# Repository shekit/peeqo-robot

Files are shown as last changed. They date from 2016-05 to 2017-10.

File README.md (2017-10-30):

# Peeqo
Thank you for making this the **~highest~ second highest voted DIY project** everr on Reddit! 
https://www.reddit.com/r/DIY/comments/5h15f4/i_built_a_desktop_robot_that_responds_entirely_in/

Check out the **video** here: https://youtu.be/ApAzIJ3jQtw

# Hardware

I have separated out the hardware elements into a seperate repo. You can find that here https://github.com/shekit/peeqo-robot-hardware

# Setting up the Pi:

This is a detailed guide on getting your Pi up and running:

### Setup up SD Card on Pi:

1. Download Raspbian Jessie with Pixel (https://www.raspberrypi.org/downloads/raspbian/)
- Kernel Version - 4.4
- Release Date - 11 - 01 - 2017 or latest version
- Version - January 2017  or latest version
2. Unzip File
- Mac OSX has problems unzipping files which unzip to more than 4gb
- Go to Terminal and unzip file with command
- tar xzvf /path/to/zip/file
3. Download Etcher from resin.io (https://etcher.io/)
4. Download SDFormatter and clean format SD card(not quick clean) -(https://www.sdcard.org/downloads/formatter_4/)
- Sometimes SD cards larger than 32GB may not work on pi
- If Pi RED LED is on, no green LED blinking, it means it cannot read the SD card
5. Transfer unzipped .img file to SD card using Etcher (etcher.io)
6. Plug SD card into Pi and boot up
7. Connect to wifi or plug in ethernet cable

### Initial Setup:

1. Go to Menu > Preferences > Raspberry Pi Config
- Set Keyboard to US
- Set Locale to your Locale
- Expand Filesystem
2. Reboot
3. Run commands in terminal to update Raspbian for recent bug fixes:
 - `sudo apt-get update` OR `sudo apt update`
 - `sudo apt-get dist-upgrade` OR `sudo apt full-upgrade`
4. Enable SSH and i2C
- `sudo raspi-config`
- Interfacing Options > SSH > Enabled
- Interfacing Options > i2c > Enabled
5. Enable overclocking or uncomment in /boot/config.txt `arm_freq=800`
6. `sudo apt install apt-transport-https`
7. Install python pillow
- `pip install pillow`
- Make sure you are using python 2.7 not 3.0+

### Update Node:

1. Raspbian ships with node v0.10.29 which will not work, have to update it
2. Remove Old Version of Node
- `sudo apt-get remove nodered -y`  (-y flag just says yes instead of requiring user input)
- `sudo apt-get remove nodejs nodejs-legacy -y`
- `sudo apt-get remove npm -y`
3. Install Latest Node Version (install version 6)
- `sudo curl -sL https://deb.nodesource.com/setup_6.x | sudo -E bash -`
- `sudo apt-get install nodejs -y`
4. Check node and npm version
- `node -v`
- Output should be v6.10.10 or higher
- `npm -v`
- Output should be 3.10.10 or higher

### Install Electron:

1. Install Electron globally (currently have v1.6.2)
- `sudo npm install -g electron`
2. If this doesn’t work
```
rm -rf ~/.electron
mkdir ~/.electron
chmod 777 ~/.electron
sudo rm /usr/bin/electron
sudo npm -g install electron
```
### Clone this repo:

```
cd ~
git clone https://github.com/shekit/peeqo-robot
```

### Start App on Boot/Startup:

1. Change into directory
 - `~/.config/autostart`
 - You may need to create this directory if it doesn't exist
2. Add and edit .desktop file with any name inside this directory
- `sudo nano peeqo.desktop`
3. Edit this file
``` 
[Desktop Entry]
	Type=Application
	Exec=./launch.sh
```
4. Create launcher script at root directory
```sudo nano launch.sh
sudo chmod +x launch.sh
```
5. Edit launch script
```
#!/bin/bash
cd /path/to/electron/app // this should be where the directory exists on your pi
sudo electron main.js
```

### Setup Mic:

1. Plug Sound Card into USB
2. Plug speaker and mic into soundcard
3. Do `arecord -l` and `aplay -l` to see the number of your device - whether it’s 0,1,2
4. Edit alsa.conf (might have to change to 1 or 2 depending on whether you have a camera plugged in)
```
sudo nano /usr/share/alsa/alsa.conf
defaults.ctl.card 0 > defaults.ctl.card 1
defaults.pcm.card 0 > defaults.pcm.card 1
defaults.pcm.device 0 > defaults.pcm.device 1
```
5. Edit aliases.conf

`sudo nano /lib/modprobe.d/aliases.conf`
- Comment out below option or it will override previous changes on startup
```
options snd-usb-audio index=-2 (comment this out with a # before)
```
- THIS MAY BE CAUSING AN ERROR, dont do this and see if it helps
- Check order modules load in
`cat /proc/asound/modules`

6. Edit .asoundrc
```
nano .asoundrc
pcm.!default{
	type asym
	playback.pcm {
		type plug
		slave.pcm “hw:1,0”  
#this first number is the number of the usb device
	}

	capture.pcm {
		type plug
		slave.pcm “hw:1,0”
 #this is the mic usb number, maybe 2 if camera is included
}
}
```
7. Check if this works instead ( this worked on one pi not running pixel)
`pcm.!default { type plug slave { pcm "hw:1,0" } } ctl.!default { type hw card 1 }`
8. If you don’t use plugs you will get following error with arecord
`arecord: set_params:1233: Sample format non available Available formats: - S16_LE`

### Setup Bluetooth:

1. `hcitool | grep ver` -- make sure it’s higher than 5.x.x
2. Stop Bluetooth Daemon bluetoothd
```
sudo systemctl stop bluetooth
sudo systemctl status bluetooth #should show status ‘quitting’
sudo systemctl disable bluetooth #for it to persist after reboot
```
3. Power up bluetooth adapter
`sudo hciconfig hci0 up`
4. Install necessary libraries
`sudo apt-get install bluetooth bluez libbluetooth-dev libudev-dev`
5. Allow to run without root/sudo
```
sudo apt-get install libcap2-bin
sudo setcap cap_net_raw+eip $(eval readlink -f `which electron`)
```
- This grants electron cap_net_raw priveleges to start/stop ble advertising
(this is not working right now)
6. Do all this before installing an app with bleno

### Remove Mouse Cursor and prevent screen from going off:

`sudo nano /etc/lightdm/lightdm.conf`
- Uncomment any line saying xserver-command=X
- Write command
`xserver-command=X -nocursor -s 0 -dpms`

### Manga Screen Settings:

```
sudo nano /boot/config.txt
hdmi_force_hotplug=1 (if not already there)
config_hdmi_boost=4
overscan_left=0
overscan_right=0
overscan_top=0
overscan_bottom=0
disable_overscan=1
display_rotate=1
	
hdmi_cvt=480 800 60 6
#hdmi_group=2
#hdmi_mode=87
#hdmi_drive=2
```

### Increase USB Current:

```
sudo nano /boot/config.txt
max_usb_current=1
```
### Run app:

```
cd /path/to/folder/electron
sudo electron main.js
```

# Steps Ahead

Yes, there's still work to be done. I will keep chipping away at it. Any contributions/feedback are welcome!

Let's make Peeqo the best community built robot ever!

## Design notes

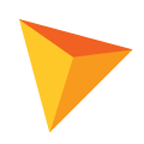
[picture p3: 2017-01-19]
cordova/www/img/xxhdpi.png

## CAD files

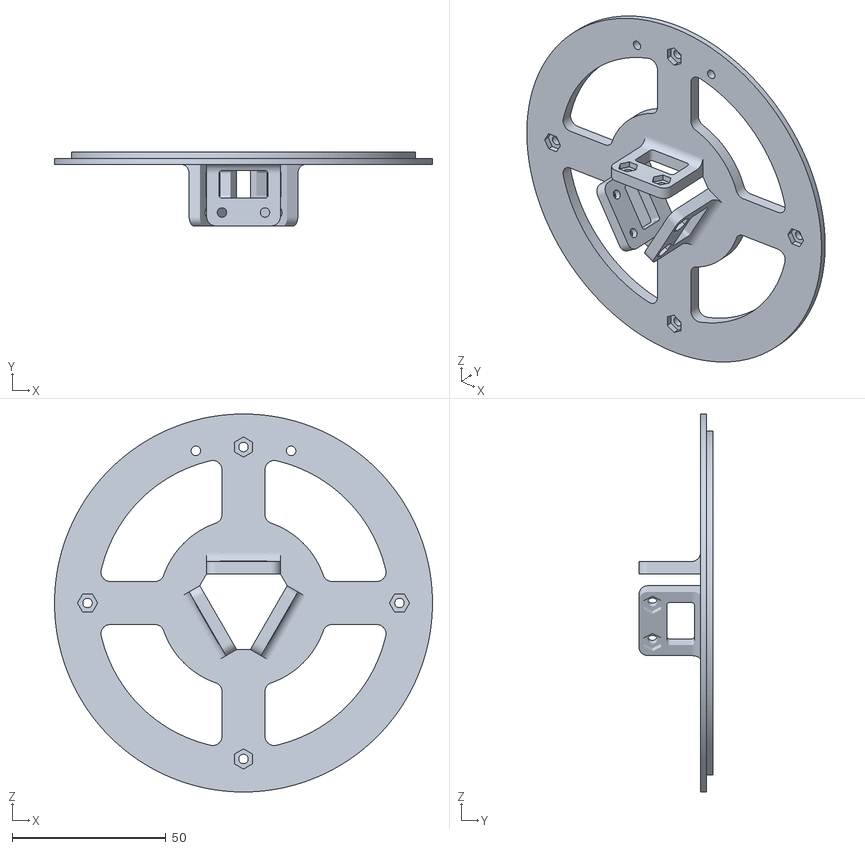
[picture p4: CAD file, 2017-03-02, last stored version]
stl_files/stewart_top.stl
123.0 x 24.0 x 123.0

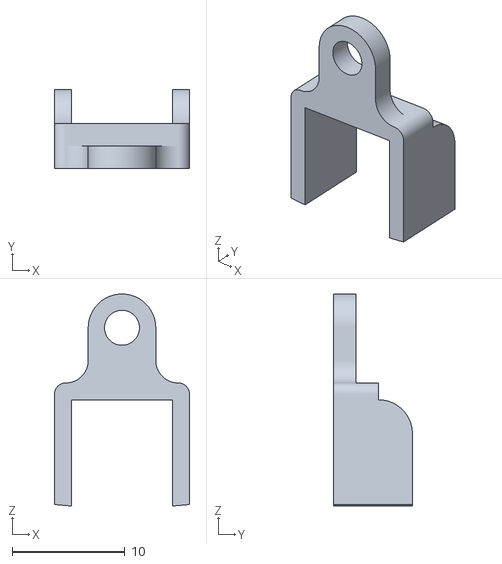
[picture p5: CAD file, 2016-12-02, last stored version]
stl_files/power_inlet_holderx1.stl
12.0 x 7.00 x 18.8

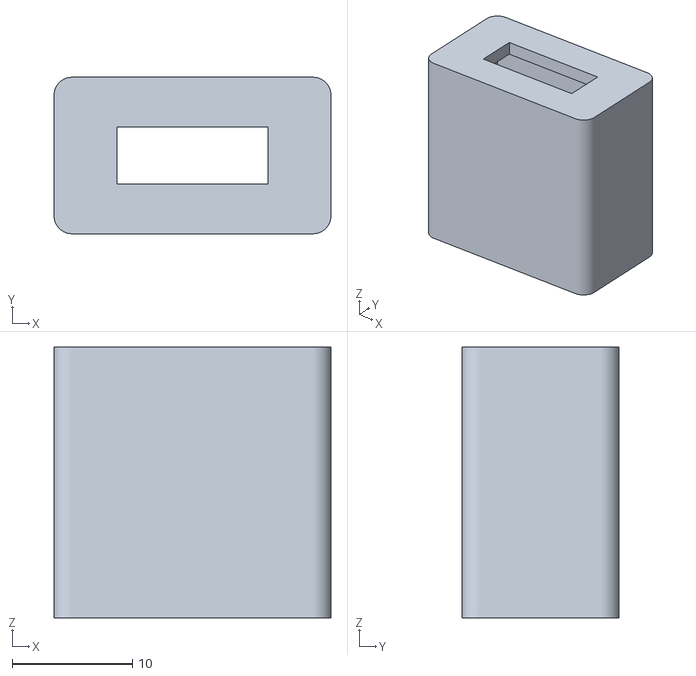
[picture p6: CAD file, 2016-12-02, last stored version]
stl_files/sabrent_sound_card_coverx1.stl
23.0 x 13.0 x 22.5

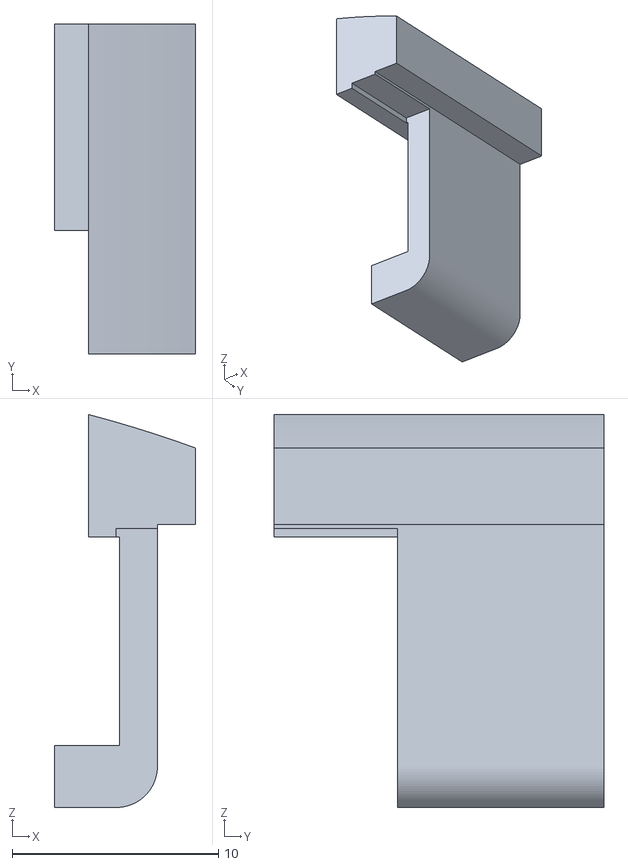
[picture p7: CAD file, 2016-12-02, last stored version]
stl_files/servo_slide_clampx3.stl
6.85 x 16.0 x 19.0

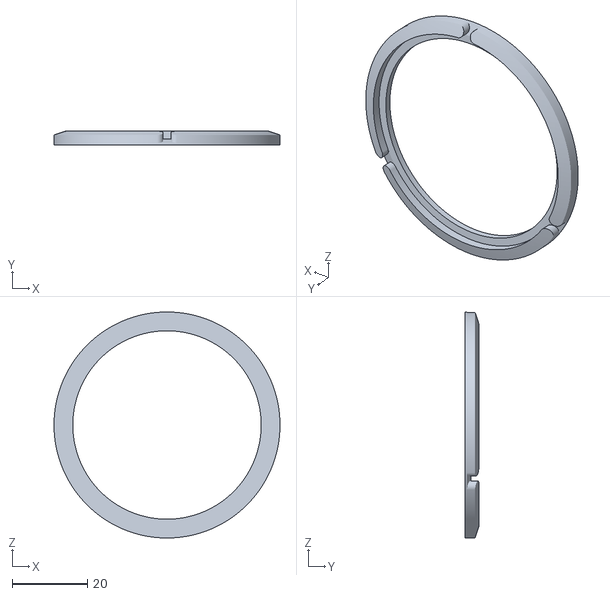
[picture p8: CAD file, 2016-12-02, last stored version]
stl_files/led_ringx1.stl
60.0 x 3.63 x 60.0

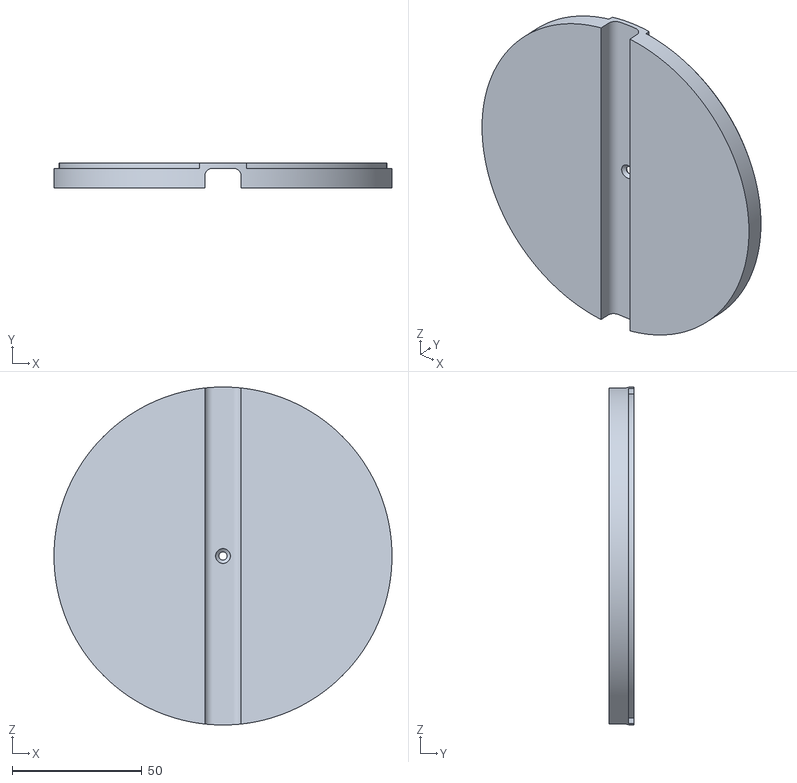
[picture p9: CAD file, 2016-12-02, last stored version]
stl_files/base_feetx1.stl
130.0 x 9.50 x 130.0

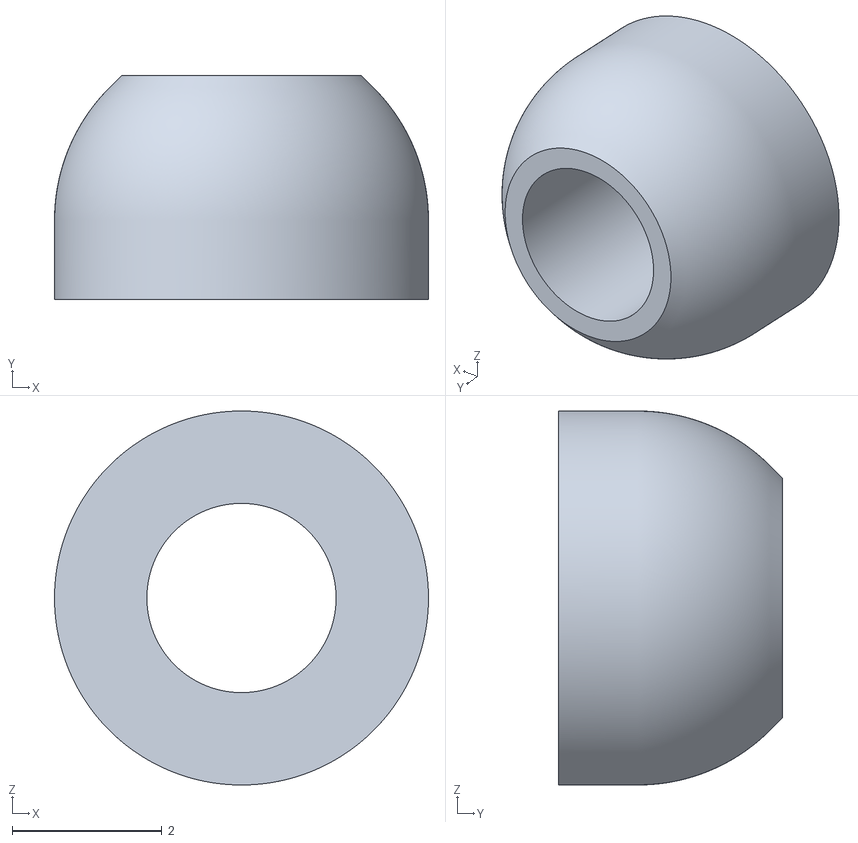
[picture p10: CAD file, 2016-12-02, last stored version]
stl_files/3mmspacerx12.stl
5.00 x 3.00 x 5.00

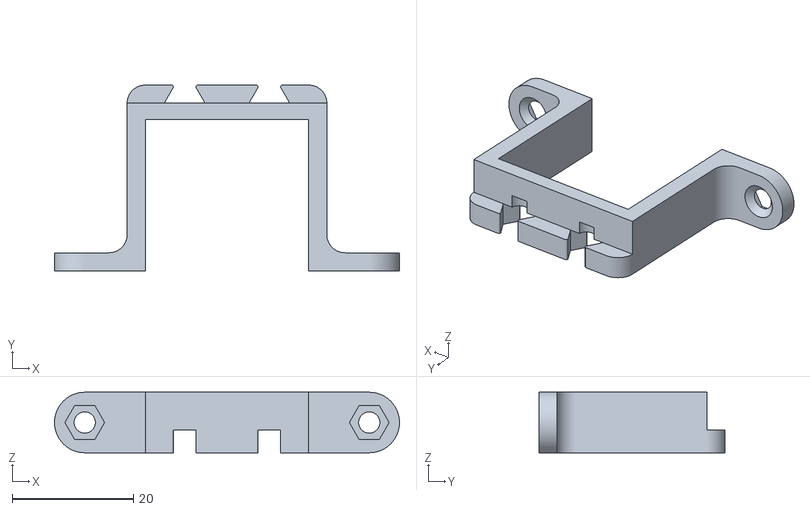
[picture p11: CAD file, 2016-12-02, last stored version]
stl_files/servo_holderx3.stl
57.0 x 30.7 x 10.0

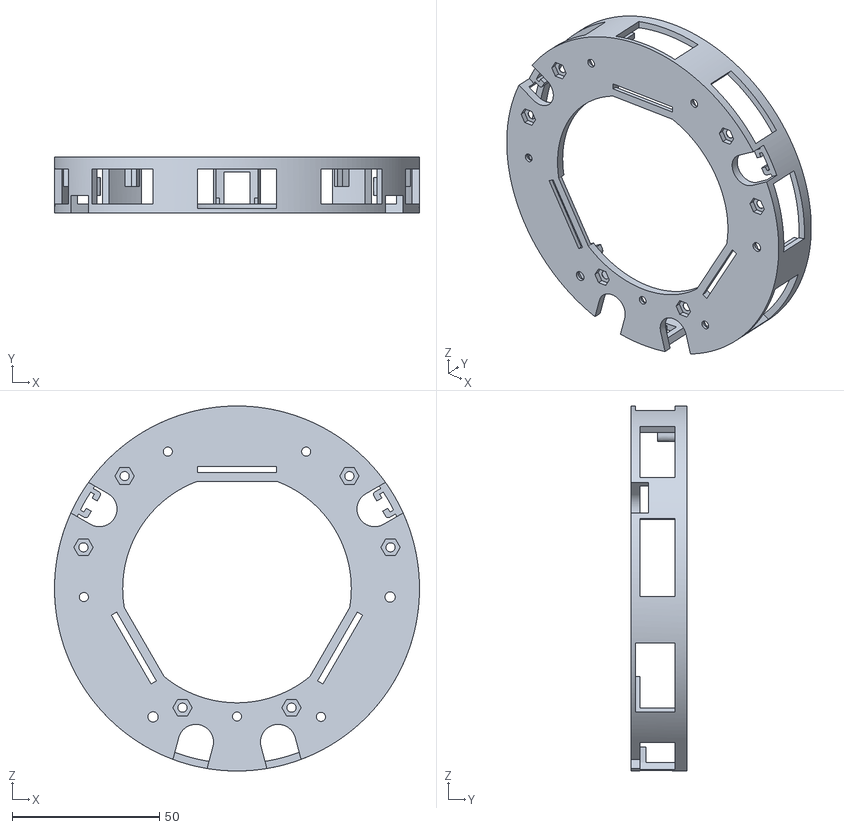
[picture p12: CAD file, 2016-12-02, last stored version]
stl_files/stewart_basex1.stl
124.0 x 19.0 x 124.0

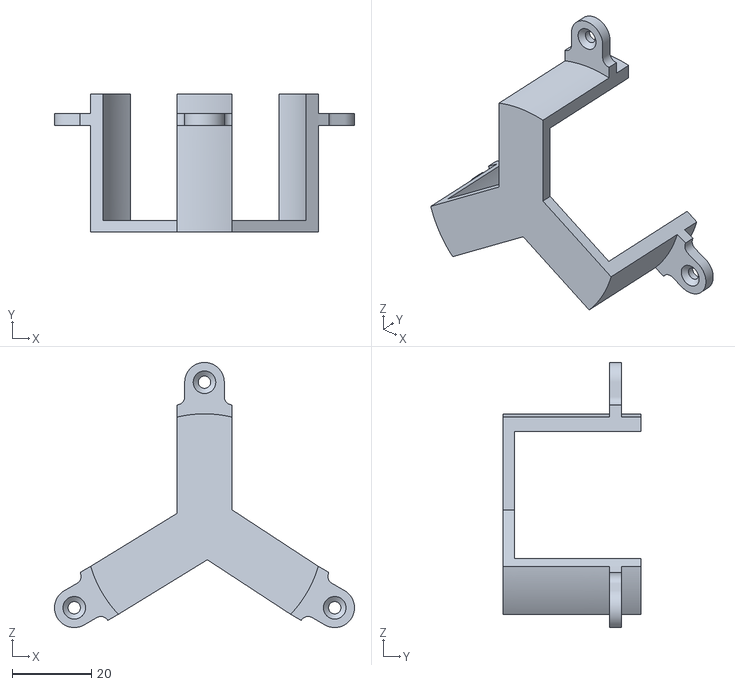
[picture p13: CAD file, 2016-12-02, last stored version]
stl_files/speaker_clampx1.stl
75.8 x 35.0 x 67.0

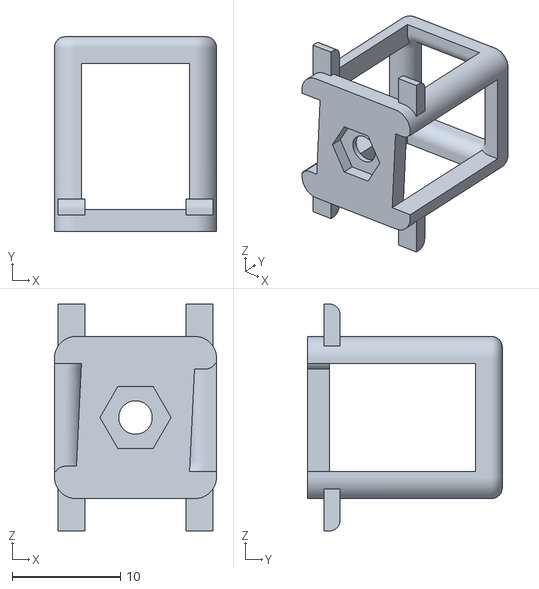
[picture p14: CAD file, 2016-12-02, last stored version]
stl_files/wire_organizerx1.stl
15.0 x 18.0 x 21.0

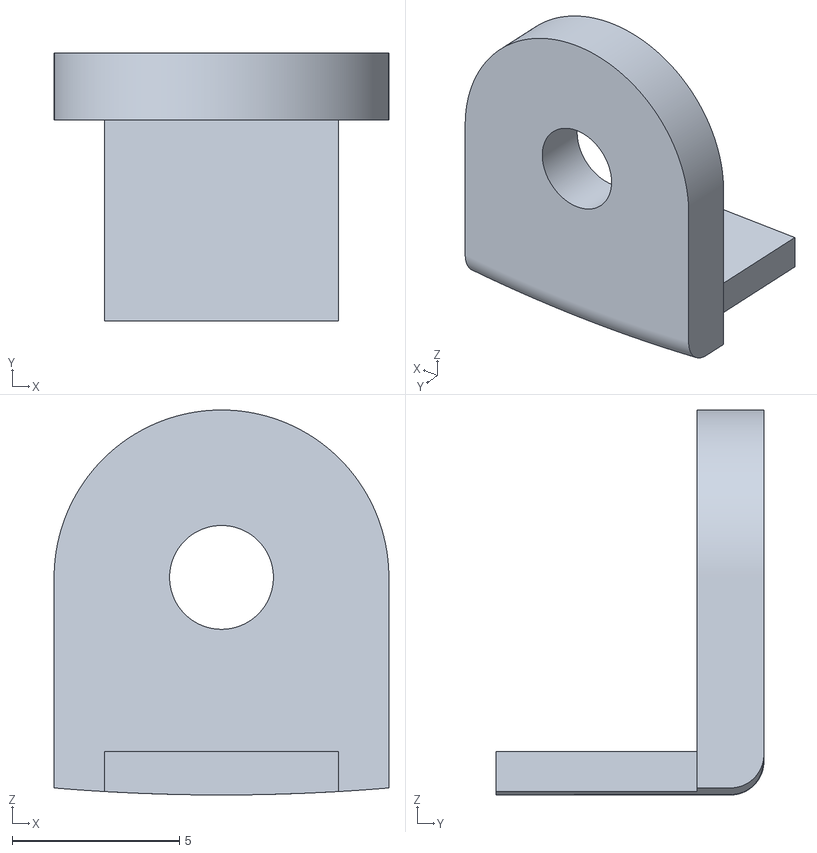
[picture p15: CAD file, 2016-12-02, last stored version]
stl_files/circuit_holderx2.stl
10.0 x 8.00 x 11.5

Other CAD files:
stl_files/servo_slide_clamp_mirrowx3.stl

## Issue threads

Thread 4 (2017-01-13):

Consider using Sonus

evancohen, 2017-01-13:
Hey @shekit, love the project. Since you're already using the snowboy node module that I wrote I thought I would recommend [Sonus](https://github.com/evancohen/sonus): It uses snowboy for keyword spotting and has built-in streaming recognition, which might make things a little easier on you, given you are trying to open source.

I currently use it in an Electron project so you have something to base it off of: https://github.com/evancohen/smart-mirror

I'd be happy to send a PR if you'd care to point me in the right direction :)

shekit, 2017-01-13:
hey @evancohen, love your project too.. still have to update this repo, been working in a test repo where I built the entire snowboy google integration only to find your library and realize you do it much better! so yes already switchin to Sonus on my test repo :)

evancohen, 2017-01-13:
Awesome! If you need any help, either adding features to Sonus (or otherwise), I'd be happy to lend a hand.

I am super passionate about (and am trying to increase awareness around) voice interfaces. Would you mind linking to Sonus from your YouTube video/imgur post? That'd be really awesome :)

shekit, 2017-01-13:
Done! Added to the imgur post under the voice recognition section :)

evancohen, 2017-01-13:
Thanks! Once things cool down a bit for you (I imagine things are a bit crazy right now) it'd be really fun to collaborate on something. Ping me sometime!

Closed 2017-01-13.

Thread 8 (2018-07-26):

Documentation of the architecture

assadollahi, 2018-07-26:
Hi thanks für sharing this awesome project, it would be cool to understand the architecture better, like:

- what is the architecture from bird's eye view?
- what kind of speech recognition do you use (is it simply google or amazon?)
- what gif server do you query
- what is the main programming language (node,js, i guess, why not python?)
- what exactly do you do with bluetooth (or why is it necessary), to control the lamp?
- how do you manage dialogs (do you use a package like Jasper)
- how do you "load spotify" on the raspberry pi (i've seen projects doing that)
- it's nice that you use arduino for controlling the servos, but people need to know how to wire it up, at least roughly (i.e. how many servos do you use and what are their functions), pictures from the inside of the neck would be nice.

cheers, keep up the good work!

shekit, 2019-07-01:
this has been moved to a new repo https://github.com/shekit/peeqo. If you have a look at the wiki it contains a tutorial on how to setup a custom command which covers a lot of these high level questions

Closed 2019-07-01.

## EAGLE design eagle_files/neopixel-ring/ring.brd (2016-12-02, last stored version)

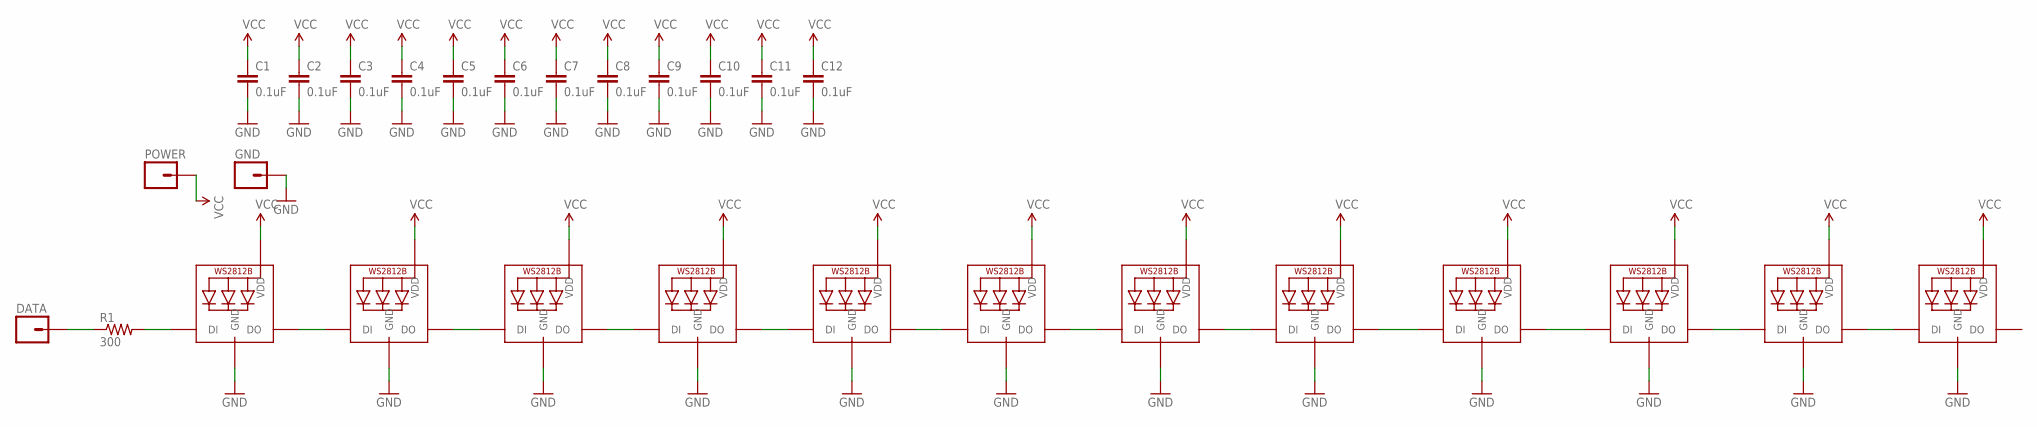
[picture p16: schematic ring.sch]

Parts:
C1, C2, C3, C4, C5, C6, C7, C8, C9, C10, C11, C12: 0.1uF; 0603-CAP
DATA: M01PTH; 1X01
GND: M01PTH; 1X01
LED1, LED2, LED3, LED4, LED5, LED6, LED7, LED8, LED9, LED10, LED11, LED12: WS2812B5050; WS2812B
POWER: M01PTH; 1X01
R1: 300; 0603-RES

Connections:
GND: C1.2, C2.2, C3.2, C4.2, C5.2, C6.2, C7.2, C8.2, C9.2, C10.2, C11.2, C12.2, GND.1, LED1.3-GND (GND), LED2.3-GND (GND), LED3.3-GND (GND), LED4.3-GND (GND), LED5.3-GND (GND), LED6.3-GND (GND), LED7.3-GND (GND), LED8.3-GND (GND), LED9.3-GND (GND), LED10.3-GND (GND), LED11.3-GND (GND), LED12.3-GND (GND)
unnamed: LED1.4-DIN (DI), R1.2
unnamed: DATA.1, R1.1
unnamed: LED1.2-DOUT (DO), LED2.4-DIN (DI)
unnamed: LED2.2-DOUT (DO), LED3.4-DIN (DI)
unnamed: LED3.2-DOUT (DO), LED4.4-DIN (DI)
unnamed: LED4.2-DOUT (DO), LED5.4-DIN (DI)
unnamed: LED5.2-DOUT (DO), LED6.4-DIN (DI)
unnamed: LED6.2-DOUT (DO), LED7.4-DIN (DI)
unnamed: LED7.2-DOUT (DO), LED8.4-DIN (DI)
unnamed: LED8.2-DOUT (DO), LED9.4-DIN (DI)
unnamed: LED9.2-DOUT (DO), LED10.4-DIN (DI)
unnamed: LED10.2-DOUT (DO), LED11.4-DIN (DI)
unnamed: LED11.2-DOUT (DO), LED12.4-DIN (DI)
VCC: C1.1, C2.1, C3.1, C4.1, C5.1, C6.1, C7.1, C8.1, C9.1, C10.1, C11.1, C12.1, LED1.1-VDD (VDD), LED2.1-VDD (VDD), LED3.1-VDD (VDD), LED4.1-VDD (VDD), LED5.1-VDD (VDD), LED6.1-VDD (VDD), LED7.1-VDD (VDD), LED8.1-VDD (VDD), LED9.1-VDD (VDD), LED10.1-VDD (VDD), LED11.1-VDD (VDD), LED12.1-VDD (VDD), POWER.1

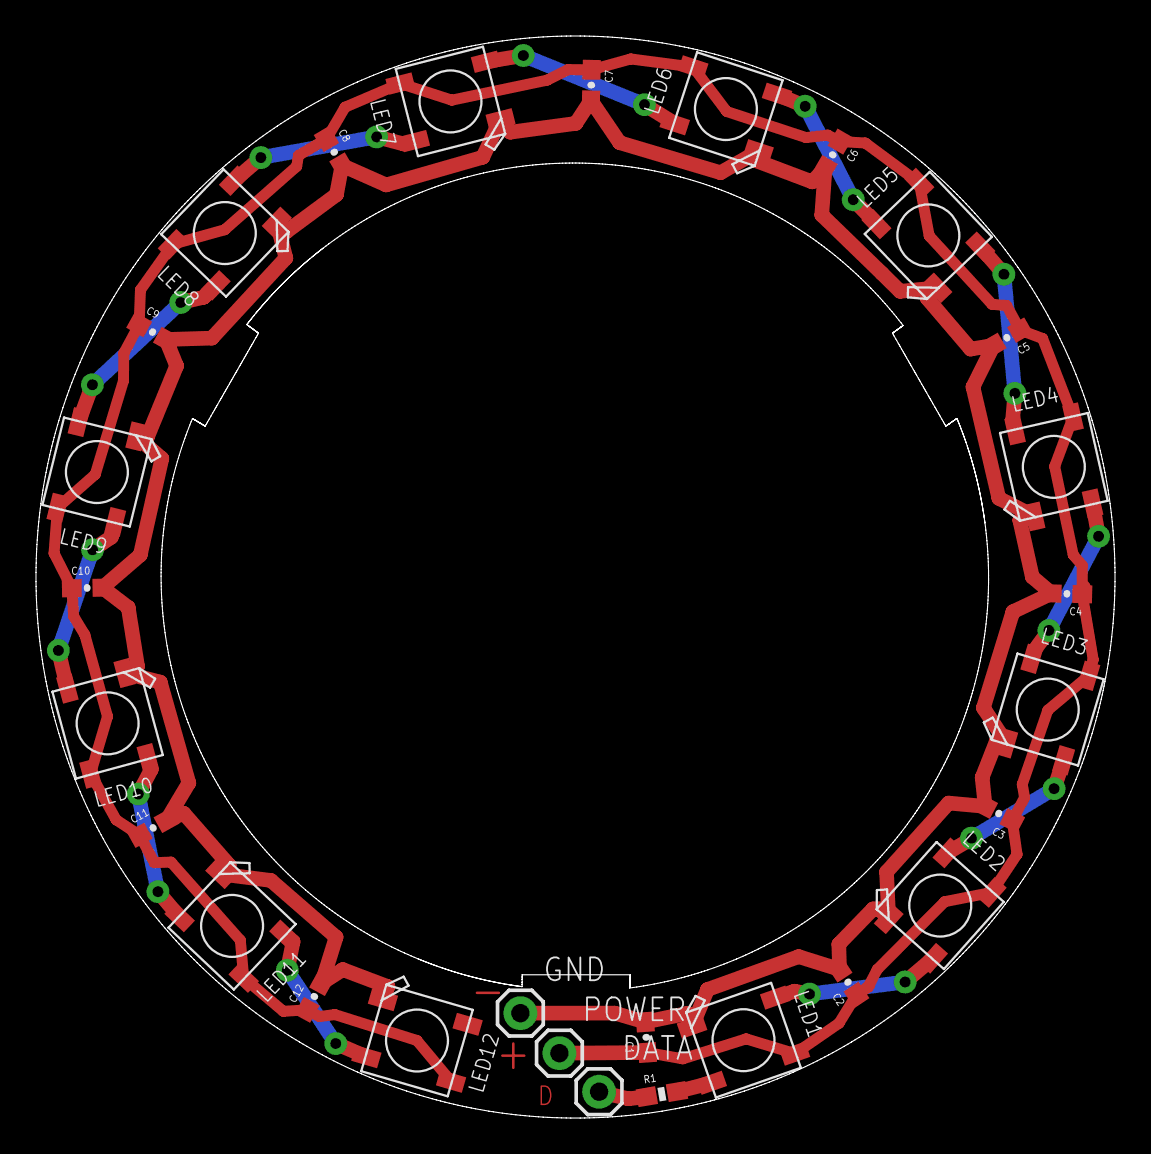
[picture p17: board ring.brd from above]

Board: 2 copper layers, 59.9 x 60.1 mm, 28 parts (0 on the bottom side), 15 nets.

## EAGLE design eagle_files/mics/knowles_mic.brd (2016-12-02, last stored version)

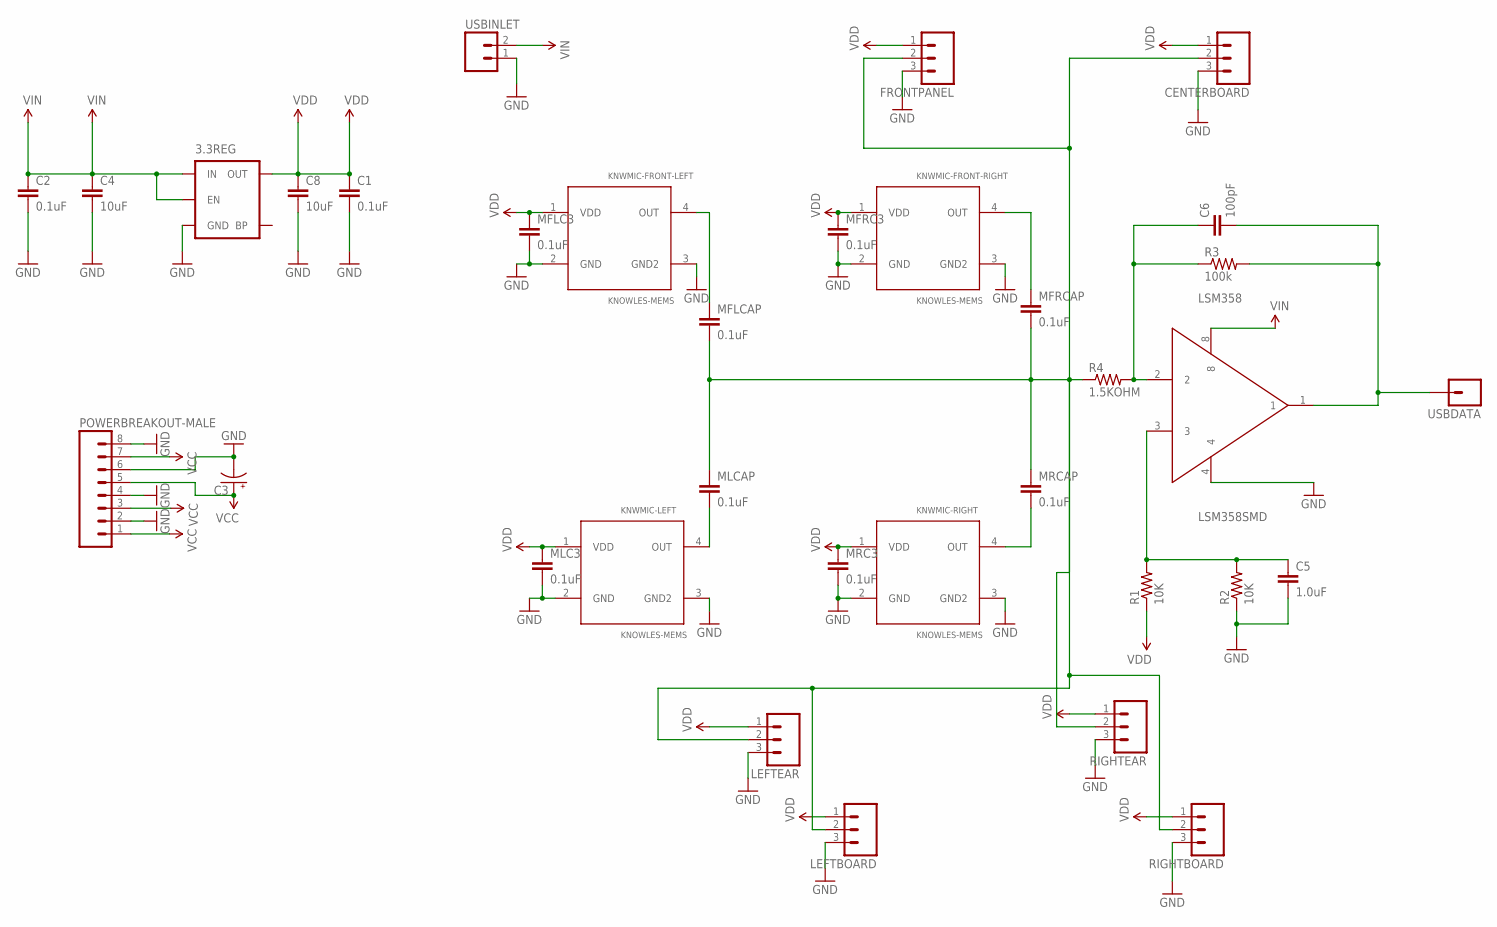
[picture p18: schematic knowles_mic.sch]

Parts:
3.3REG: MIC52053.3V; SOT23-5
C1, C2: 0.1uF; 0603-CAP
C3: CAP_POLG; PANASONIC_G
C4, C8: 10uF; 0603-CAP
C5: 1.0uF; 0603-CAP
C6: 100pF; 0603-CAP
CENTERBOARD: M03PTH; 1X03
FRONTPANEL: M03PTH; 1X03
KNWMIC-FRONT-LEFT: KNOWLES-MEMS; MEMS-SPU0410
KNWMIC-FRONT-RIGHT: KNOWLES-MEMS; MEMS-SPU0410
KNWMIC-LEFT: KNOWLES-MEMS; MEMS-SPU0410
KNWMIC-RIGHT: KNOWLES-MEMS; MEMS-SPU0410
LEFTBOARD: M03PTH; 1X03
LEFTEAR: M03PTH; 1X03
LSM358: LSM358SMD; SOP-8L
MFLC3: 0.1uF; 0603-CAP
MFLCAP: 0.1uF; 0603-CAP
MFRC3: 0.1uF; 0603-CAP
MFRCAP: 0.1uF; 0603-CAP
MLC3: 0.1uF; 0603-CAP
MLCAP: 0.1uF; 0603-CAP
MRC3: 0.1uF; 0603-CAP
MRCAP: 0.1uF; 0603-CAP
POWERBREAKOUT-MALE: M08SMD-STRAIGHT-FEMALE; 1X08_SMD
R1, R2: 10K; 0603-RES
R3: 100k; 0603-RES
R4: 1.5KOHM; 0603
RIGHTBOARD: M03PTH; 1X03
RIGHTEAR: M03PTH; 1X03
USBDATA: M01PTH; 1X01
USBINLET: M02PTH; 1X02

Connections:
GND: 3.3REG.2 (GND), C1.2, C2.2, C3.-, C4.2, C5.2, C8.2, CENTERBOARD.3, FRONTPANEL.3, KNWMIC-FRONT-LEFT.2 (GND), KNWMIC-FRONT-LEFT.3 (GND2), KNWMIC-FRONT-RIGHT.2 (GND), KNWMIC-FRONT-RIGHT.3 (GND2), KNWMIC-LEFT.2 (GND), KNWMIC-LEFT.3 (GND2), KNWMIC-RIGHT.2 (GND), KNWMIC-RIGHT.3 (GND2), LEFTBOARD.3, LEFTEAR.3, LSM358.4, MFLC3.2, MFRC3.2, MLC3.2, MRC3.2, POWERBREAKOUT-MALE.2, POWERBREAKOUT-MALE.4, POWERBREAKOUT-MALE.6, POWERBREAKOUT-MALE.8, R2.1, RIGHTBOARD.3, RIGHTEAR.3, USBINLET.1
unnamed: CENTERBOARD.2, FRONTPANEL.2, LEFTBOARD.2, LEFTEAR.2, MFLCAP.2, MFRCAP.2, MLCAP.1, MRCAP.1, R4.1, RIGHTBOARD.2, RIGHTEAR.2
unnamed: KNWMIC-RIGHT.4 (OUT), MRCAP.2
unnamed: KNWMIC-FRONT-LEFT.4 (OUT), MFLCAP.1
unnamed: KNWMIC-LEFT.4 (OUT), MLCAP.2
unnamed: C5.1, LSM358.3, R1.2, R2.2
unnamed: KNWMIC-FRONT-RIGHT.4 (OUT), MFRCAP.1
unnamed: C6.1, LSM358.2, R3.1, R4.2
unnamed: C6.2, LSM358.1, R3.2, USBDATA.1
VCC: C3.+, POWERBREAKOUT-MALE.1, POWERBREAKOUT-MALE.3, POWERBREAKOUT-MALE.5, POWERBREAKOUT-MALE.7
VDD: 3.3REG.5 (OUT), C1.1, C8.1, CENTERBOARD.1, FRONTPANEL.1, KNWMIC-FRONT-LEFT.1 (VDD), KNWMIC-FRONT-RIGHT.1 (VDD), KNWMIC-LEFT.1 (VDD), KNWMIC-RIGHT.1 (VDD), LEFTBOARD.1, LEFTEAR.1, MFLC3.1, MFRC3.1, MLC3.1, MRC3.1, R1.1, RIGHTBOARD.1, RIGHTEAR.1
VIN: 3.3REG.1 (IN), 3.3REG.3 (EN), C2.1, C4.1, LSM358.8, USBINLET.2

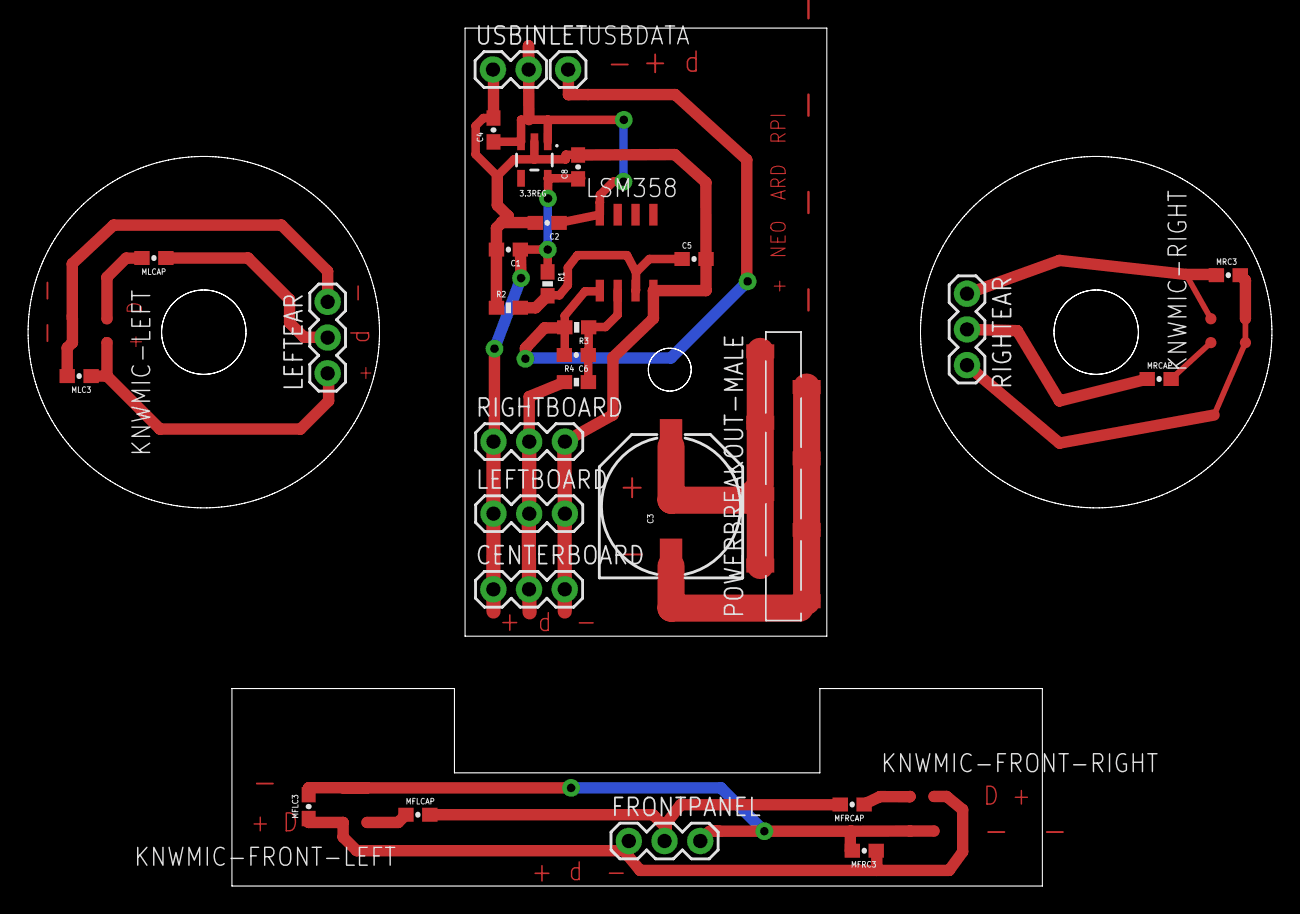
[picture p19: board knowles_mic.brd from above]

Board: 2 copper layers, 88.5 x 61.0 mm, 34 parts (0 on the bottom side), 12 nets.

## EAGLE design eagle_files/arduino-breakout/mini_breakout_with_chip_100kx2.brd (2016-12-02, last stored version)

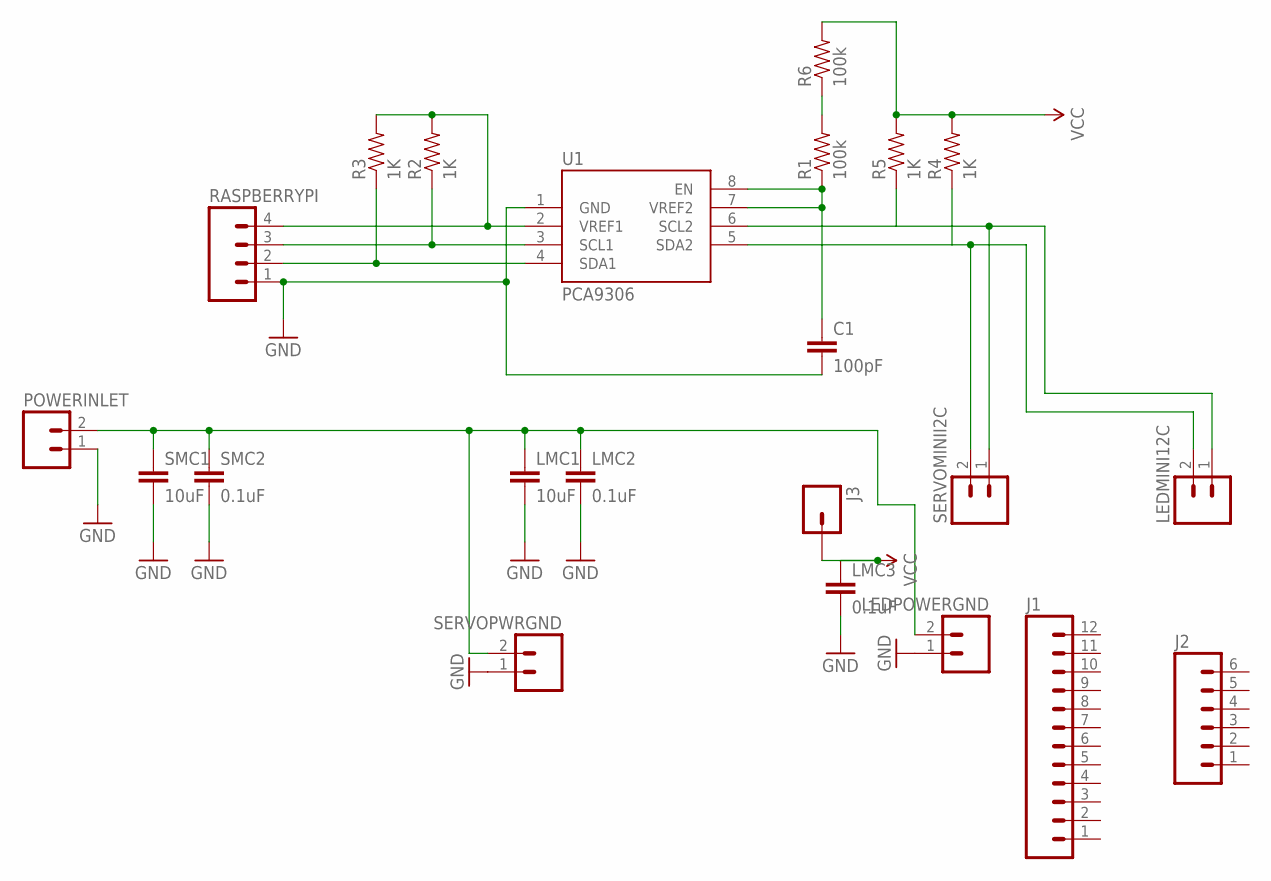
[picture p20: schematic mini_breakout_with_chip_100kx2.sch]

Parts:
C1: 100pF; 0603-CAP
J1: M121X12_NO_SILK_KIT; 1X12_NO_SILK_KIT
J2: M06NO_SILK_YES_STOP; 1X06_NO_SILK_YES_STOP
J3: M01NOSILK-KIT; 1X01NS-KIT
LEDMINI12C: M02PTH; 1X02
LEDPOWERGND: M021X02_NO_SILK; 1X02_NO_SILK
LMC1: 10uF; 0603-CAP
LMC2, LMC3: 0.1uF; 0603-CAP
POWERINLET: M02PTH; 1X02
R1, R6: 100k; 0603-RES
R2, R3, R4, R5: 1K; 0603-RES
RASPBERRYPI: M04PTH; 1X04
SERVOMINII2C: M02PTH; 1X02
SERVOPWRGND: M021X02_NO_SILK; 1X02_NO_SILK
SMC1: 10uF; 0603-CAP
SMC2: 0.1uF; 0603-CAP
U1: PCA9306; PSOP-8

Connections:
GND: C1.2, LEDPOWERGND.1, LMC1.2, LMC2.2, LMC3.2, POWERINLET.1, RASPBERRYPI.1, SERVOPWRGND.1, SMC1.2, SMC2.2, U1.1 (GND)
unnamed: R2.2, R3.2, RASPBERRYPI.4, U1.2 (VREF1)
unnamed: R2.1, RASPBERRYPI.3, U1.3 (SCL1)
unnamed: R3.1, RASPBERRYPI.2, U1.4 (SDA1)
unnamed: LEDPOWERGND.2, LMC1.1, LMC2.1, POWERINLET.2, SERVOPWRGND.2, SMC1.1, SMC2.1
unnamed: C1.1, R1.1, U1.7 (VREF2), U1.8 (EN)
unnamed: LEDMINI12C.1, R5.1, SERVOMINII2C.1, U1.6 (SCL2)
unnamed: LEDMINI12C.2, R4.1, SERVOMINII2C.2, U1.5 (SDA2)
unnamed: R1.2, R6.1
VCC: J3.1, LMC3.1, R4.2, R5.2, R6.2

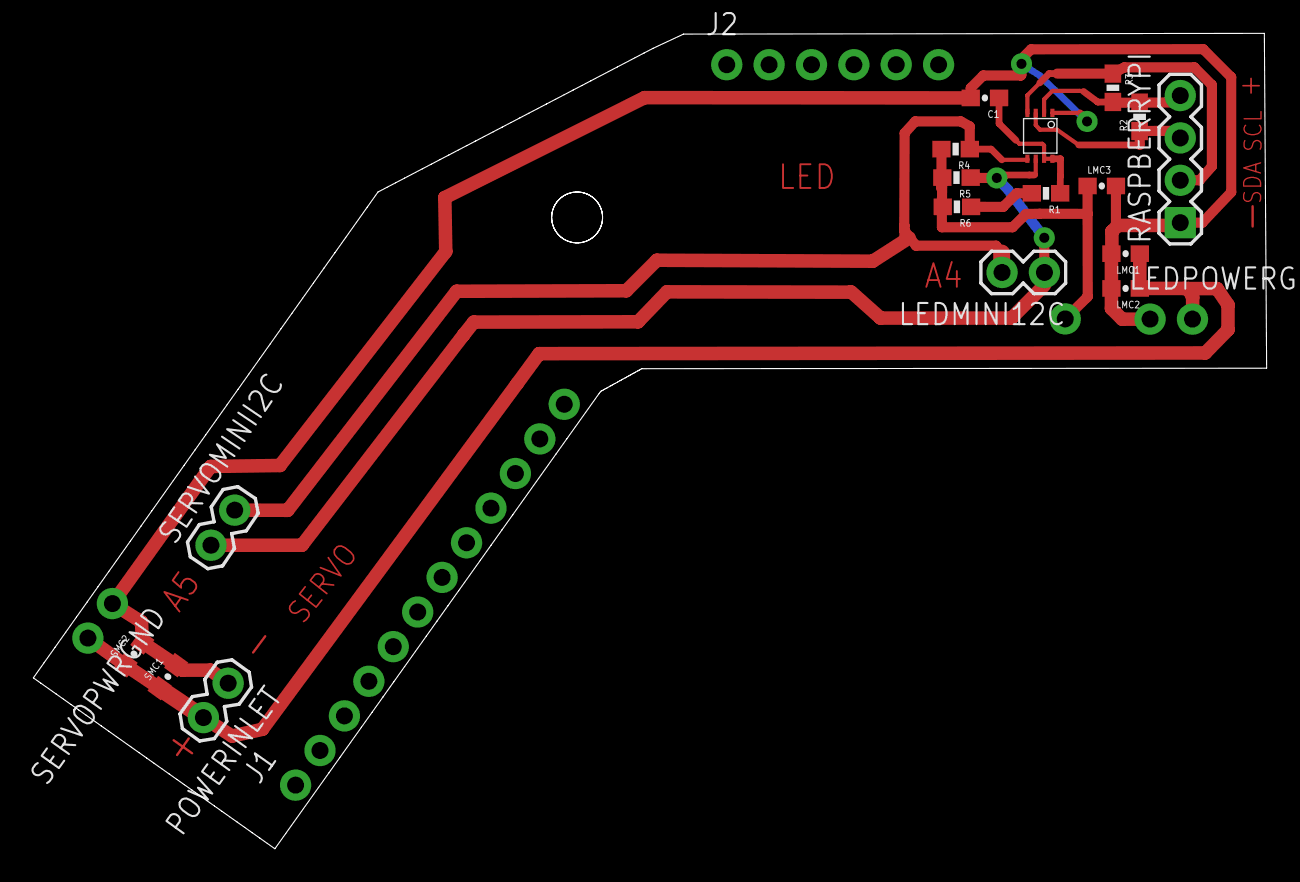
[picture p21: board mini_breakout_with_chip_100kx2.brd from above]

Board: 2 copper layers, 73.9 x 48.9 mm, 22 parts (0 on the bottom side), 10 nets.

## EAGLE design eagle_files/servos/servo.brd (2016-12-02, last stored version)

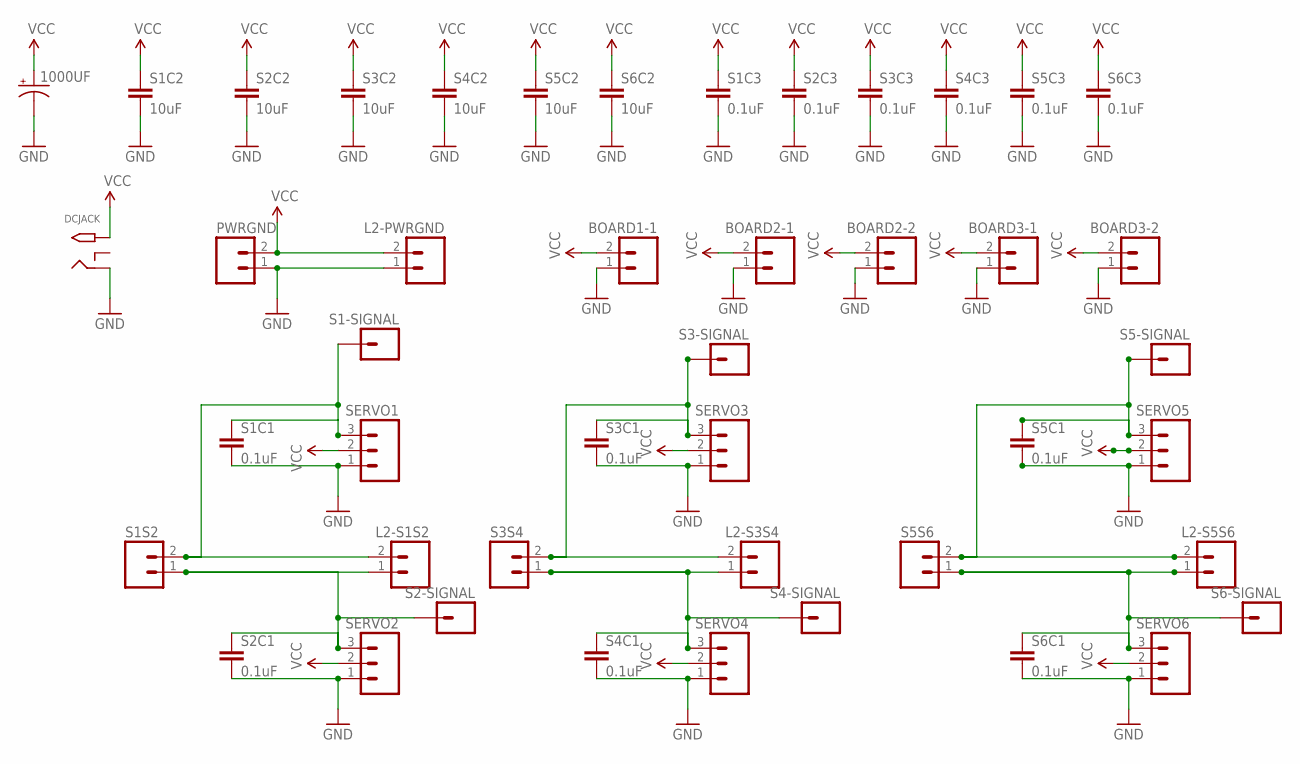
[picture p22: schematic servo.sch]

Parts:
1000UF: CAP_POLG; PANASONIC_G
BOARD1-1, BOARD2-1, BOARD2-2, BOARD3-1, BOARD3-2: M02PTH; 1X02
DCJACK: 2.1MMJACKTHM; PJ-102A
L2-PWRGND, L2-S1S2, L2-S3S4, L2-S5S6: M02PTH; 1X02
PWRGND: M02PTH; 1X02
S1-SIGNAL, S2-SIGNAL, S3-SIGNAL, S4-SIGNAL, S5-SIGNAL, S6-SIGNAL: M01PTH; 1X01
S1C1, S1C3, S2C1, S2C3, S3C1, S3C3, S4C1, S4C3, S5C1, S5C3, S6C1, S6C3: 0.1uF; 0603-CAP
S1C2, S2C2, S3C2, S4C2, S5C2, S6C2: 10uF; 0603-CAP
S1S2, S3S4, S5S6: M02PTH; 1X02
SERVO1, SERVO2, SERVO3, SERVO4, SERVO5, SERVO6: M03PTH; 1X03

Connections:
GND: 1000UF.-, BOARD1-1.1, BOARD2-1.1, BOARD2-2.1, BOARD3-1.1, BOARD3-2.1, DCJACK.RING, L2-PWRGND.1, PWRGND.1, S1C1.2, S1C2.2, S1C3.2, S2C1.2, S2C2.2, S2C3.2, S3C1.2, S3C2.2, S3C3.2, S4C1.2, S4C2.2, S4C3.2, S5C1.2, S5C2.2, S5C3.2, S6C1.2, S6C2.2, S6C3.2, SERVO1.1, SERVO2.1, SERVO3.1, SERVO4.1, SERVO5.1, SERVO6.1
unnamed: L2-S3S4.2, S3-SIGNAL.1, S3C1.1, S3S4.2, SERVO3.3
unnamed: L2-S1S2.2, S1-SIGNAL.1, S1C1.1, S1S2.2, SERVO1.3
unnamed: L2-S3S4.1, S3S4.1, S4-SIGNAL.1, S4C1.1, SERVO4.3
unnamed: L2-S1S2.1, S1S2.1, S2-SIGNAL.1, S2C1.1, SERVO2.3
unnamed: L2-S5S6.2, S5-SIGNAL.1, S5C1.1, S5S6.2, SERVO5.3
unnamed: L2-S5S6.1, S5S6.1, S6-SIGNAL.1, S6C1.1, SERVO6.3
VCC: 1000UF.+, BOARD1-1.2, BOARD2-1.2, BOARD2-2.2, BOARD3-1.2, BOARD3-2.2, DCJACK.TIP, L2-PWRGND.2, PWRGND.2, S1C2.1, S1C3.1, S2C2.1, S2C3.1, S3C2.1, S3C3.1, S4C2.1, S4C3.1, S5C2.1, S5C3.1, S6C2.1, S6C3.1, SERVO1.2, SERVO2.2, SERVO3.2, SERVO4.2, SERVO5.2, SERVO6.2

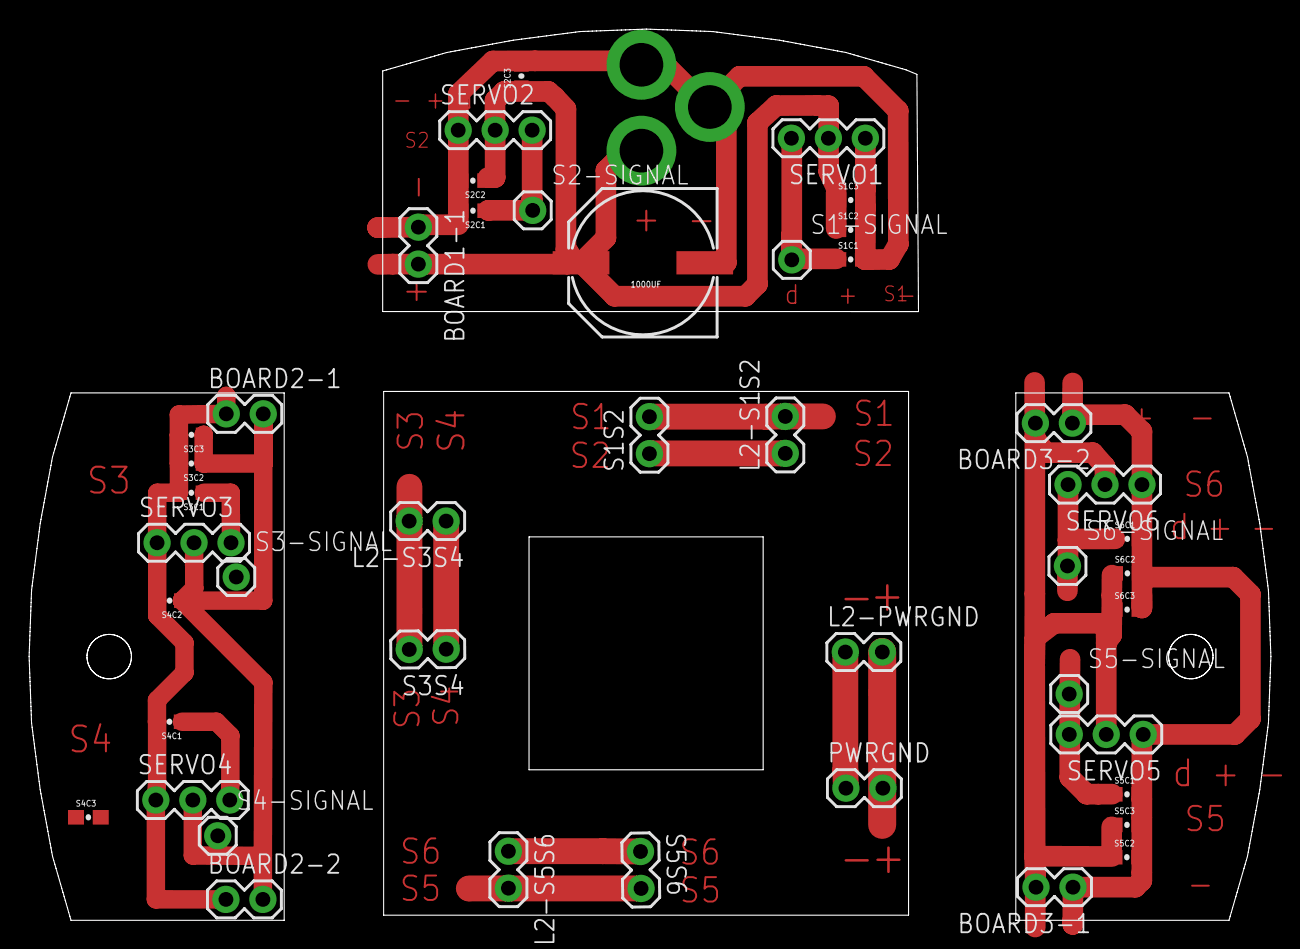
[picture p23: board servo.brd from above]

Board: 2 copper layers, 85.3 x 61.2 mm, 45 parts (1 on the bottom side), 8 nets.

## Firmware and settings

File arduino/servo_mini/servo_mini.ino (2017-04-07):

#include <Wire.h>
#include <Servo.h>
#include "ServoEaser.h"

#define I2C_ADDR 0x07

const int numServos = 6;

int servoPins[6] = {2,3,4,5,6,7};

int servoFrameMillis = 20; // min time between servo updates

int easeDuration = 1000; //default duration

int easing1 = 500;
int easing2 = 1000;
int easing3 = 1500;
int easing4 = 2000;
int easing5 = 3000;
int easing7 = 200;

boolean bounceAnimation = false;


Servo servo[6];
ServoEaser servoEaser[6];

// EASING FUNCTIONS

float easeInOutQuad (float t, float b, float c, float d) {
	if ((t/=d/2) < 1) return c/2*t*t + b;
	return -c/2 * ((--t)*(t-2) - 1) + b;
}

float easeInOutCubic (float t, float b, float c, float d) {
	if ((t/=d/2) < 1) return c/2*t*t*t + b;
	return c/2*((t-=2)*t*t + 2) + b;
}

float easeInOutQuart (float t, float b, float c, float d) {
	if ((t/=d/2) < 1) return c/2*t*t*t*t + b;
	return -c/2 * ((t-=2)*t*t*t - 2) + b;
}

float easeInOutQuint (float t, float b, float c, float d) {
	if ((t/=d/2) < 1) return c/2*t*t*t*t*t + b;
	return c/2*((t-=2)*t*t*t*t + 2) + b;
}

float easeOutBounce (float t, float b, float c, float d) {
	if ((t/=d) < (1/2.75)) {
		return c*(7.5625*t*t) + b;
	} else if (t < (2/2.75)) {
		return c*(7.5625*(t-=(1.5/2.75))*t + .75) + b;
	} else if (t < (2.5/2.75)) {
		return c*(7.5625*(t-=(2.25/2.75))*t + .9375) + b;
	} else {
		return c*(7.5625*(t-=(2.625/2.75))*t + .984375) + b;
	}
}

void setup() {
  // put your setup code here, to run once:
  Wire.begin(I2C_ADDR);
  Wire.onReceive(receiveEvent);
  
  for(int i=0;i<numServos;i++){
     servo[i].attach(servoPins[i]); 
  }
  
  for(int i=0;i<numServos;i++){
    servoEaser[i].begin(servo[i], servoFrameMillis);
    servoEaser[i].useMicroseconds(true);
    servoEaser[i].setEasingFunc(easeInOutCubic);
  }
  
  resetServos();
  
}

void loop() {

  for(int i=0;i<numServos;i++){
     servoEaser[i].update(); 
  }

}

void receiveEvent(int howMany){
   
   uint8_t myAngles[numServos]; 
    
   int i = -1; //set this to -1 because first byte is command sent from node which i dont want 
   
   while(Wire.available()>0){
      uint8_t c = Wire.read();
      
      // use cmd parameter from node to set duration of easing
      // since they are so small i can expect servo angles to not conflict with these
      
      switch(c){
         case 1:
            easeDuration = easing1;
            if(bounceAnimation){
              resetEasing();
            } 
            break;
         case 2:
            easeDuration = easing2;
            if(bounceAnimation){
              resetEasing();
            } 
            break;
           
        case 3:
            easeDuration = easing3;
           if(bounceAnimation){
              resetEasing();
            } 
            break;
        case 4:
            easeDuration = easing4;
            if(bounceAnimation){
              resetEasing();
            }
            break;
        case 5:
            easeDuration = easing5;
            if(bounceAnimation){
              resetEasing();
            }
            break;
        case 6:
            easeDuration = easing2;
            bounceAnimation = true;
            for(int i=0;i<numServos;i++){
              servoEaser[i].setEasingFunc(easeOutBounce);
            }
            break;
        case 7:
            easeDuration = easing7;
            if(bounceAnimation){
              resetEasing();
            }
            break;
        default:
            break;
          
      }
      
      // define a cmd or char to reset servos
//      if(c==4){
//         resetServos();
//      }
       
      // this is done only if the bytes dont match the cmd parameter
      // helps eliminate first cmd para sent from node
      if(c>6){
         myAngles[i] = c;
      } 
      
      i++;
   }
   
   for(uint8_t i=0;i<sizeof(myAngles)/sizeof(uint8_t);i+=1){
      runServo(i, myAngles[i]); 
   }
}

void resetEasing(){
  bounceAnimation = false;
  for(int i=0;i<numServos;i++){
     servoEaser[i].setEasingFunc(easeInOutCubic);
  }
}

void runServo(uint8_t servoNum, uint8_t angle){
    servoEaser[servoNum].easeTo(angle, easeDuration);
}

void resetServos(){
  
  // these values were calibrated for each servo
  
  servo[0].writeMicroseconds(1450); // used to be 1515
  servo[1].writeMicroseconds(1540); // used to be 1485
  servo[2].writeMicroseconds(1465);
  servo[3].writeMicroseconds(1455);
  servo[4].writeMicroseconds(1450);
  servo[5].writeMicroseconds(1500);
}

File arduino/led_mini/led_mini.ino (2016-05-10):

#include <Wire.h>
#include <Adafruit_NeoPixel.h>

#define PIXEL_PIN 6
#define PIXEL_COUNT 12
#define RING_BRIGHTNESS 64

#define I2C_ADDR 0x04

Adafruit_NeoPixel ring = Adafruit_NeoPixel(PIXEL_COUNT, PIXEL_PIN, NEO_GRB + NEO_KHZ800);

unsigned long previousMillis=0;

int animationCount = 0;
boolean limitAnimation = false;

// WIPE ANIMATION
unsigned long wipeInterval=50;
int currentPixel = 0;
int numWipes = 3;

// FADE ANIMATION
int fadeInterval = 20;
int numFades = 8;
int r = 0;
int rspeed = 5;
int g = 0;
int gspeed = 5;
int b = 0;
int bspeed = 5;

// BLINK ANIMATION
unsigned long blinkinterval = 300;
boolean lightsOn = false;
int numBlinks = 6;

// LED STATES
// add all to setStatesToFalse function
boolean red = false;
boolean green = false;
boolean blue = false;
boolean black = false;
boolean off = false;
boolean fadeRed = false;
boolean fadeGreen = false;
boolean fadeBlue = false;
boolean redBlink = false;
boolean greenBlink = false;
boolean blueBlink = false;

// colors
const uint32_t redColor = ring.Color(255,0,0);
const uint32_t greenColor = ring.Color(0,255,0);
const uint32_t blueColor = ring.Color(0,0,255);
const uint32_t offColor = ring.Color(0,0,0);

void setup() {
  
  Wire.begin(I2C_ADDR);
  Wire.onReceive(receiveEvent);
  
  // turn on for debugging
  //Serial.begin(9600);
  
  ring.begin();
  ring.setBrightness(RING_BRIGHTNESS);
  switchOff();
}

void loop() {
  // DEBUG CODE
//  if(Serial.available()>0){
//     char i = Serial.read();
//     
//     switch(i){
//        case 'r':
//          setStatesToFalse()
//           red = true;
//           break;
//        case 'g':
//          setStatesToFalse()
//           green = true;
//           break;
//        case 'b':
//          setStatesToFalse()
//           blue = true;
//           break; 
//        case 'o':
//          setStatesToFalse()
//           off = true;
//           break;
//        case 't':
//          setStatesToFalse()
//           blinky = true;
//           break;
//        case 'p':
//          setStatesToFalse()
//           rainbow = true;
//           break;
//        case 'f':
//          setStatesToFalse()
//           fade = true;
//           break;
//        default:
//          break;
//     }  
//  }
  
  
  //i2c commands set these states
  
  if(red){
    if(millis()-previousMillis >= wipeInterval){
       previousMillis = millis();
       colorWipeMillis(redColor, limitAnimation); 
    }
  }
  
  if(green){
    if(millis()-previousMillis >= wipeInterval){
       previousMillis = millis();
       colorWipeMillis(greenColor, limitAnimation); 
    }
  }
  
  if(blue){
    if(millis()-previousMillis >= wipeInterval){
       previousMillis = millis();
       colorWipeMillis(blueColor, limitAnimation); 
    }
  }
  
  if(black){
    if(millis()-previousMillis >= wipeInterval){
       previousMillis = millis();
       colorWipeMillis(offColor, true); 
    }
  }
  
  if(redBlink){
      if(millis()-previousMillis >= blinkinterval){
         previousMillis = millis();
         if(lightsOn == false){
           lightsOn = true;
         } else {
           lightsOn = false; 
         }
         
         lightsBlink(lightsOn, redColor, limitAnimation);
       }
  }
  
  if(greenBlink){
      if(millis()-previousMillis >= blinkinterval){
         previousMillis = millis();
         if(lightsOn == false){
           lightsOn = true;
         } else {
           lightsOn = false; 
         }
         
         lightsBlink(lightsOn, greenColor, limitAnimation);
       }
  }
  
  if(blueBlink){
      if(millis()-previousMillis >= blinkinterval){
         previousMillis = millis();
         if(lightsOn == false){
           lightsOn = true;
         } else {
           lightsOn = false; 
         }
         
         lightsBlink(lightsOn, blueColor, limitAnimation);
       }
  }
    
  if(fadeRed){
    if(millis()-previousMillis >= fadeInterval){
       previousMillis = millis();
       fadeRedLights(limitAnimation);
    }
  }
  
  if(fadeGreen){
    if(millis()-previousMillis >= fadeInterval){
       previousMillis = millis();
       fadeGreenLights(limitAnimation);
    }
  }
  
  if(fadeBlue){
    if(millis()-previousMillis >= fadeInterval){
       previousMillis = millis();
       fadeBlueLights(limitAnimation);
    }
  }
  
  if(off){
    switchOff();
  }
  
}

void lightsBlink(boolean lightState, uint32_t c, boolean limitBlinks){
   if(lightState==true){
      for(uint16_t i=0; i<ring.numPixels(); i++) {
        ring.setPixelColor(i, c);
        ring.show();
      }  
   } else {
       for(uint16_t i=0; i<ring.numPixels(); i++) {
        ring.setPixelColor(i, offColor);
        ring.show();
      }
   }
   
   if(limitBlinks){
     animationCount++;
     
     if(animationCount >= numBlinks){
        setStatesToFalse(); 
     }
   }
}

void colorWipeMillis(uint32_t c, boolean limitWipes){
   ring.setPixelColor(currentPixel, c);
   ring.show();
   currentPixel++;
   if(currentPixel >= PIXEL_COUNT){
      animationCount++;
      currentPixel = 0; 
      for(uint16_t i=0; i<ring.numPixels(); i++) {
        ring.setPixelColor(i, offColor);
        ring.show();
      }
   }
   
   if(limitWipes){
     if(animationCount >= numWipes){
        setStatesToFalse();
     }
   }
}

void fadeRedLights(boolean limitFade){
   
   for(int i=0; i<ring.numPixels();i++){
      ring.setPixelColor(i,ring.Color(r,0,0));
      ring.show();
   } 
   
   r+=rspeed;
   
   if(r >= 255 || r<=0){
      rspeed *= -1; 
      
      if(limitFade){
          animationCount++;
          if(animationCount >= numFades){
            setStatesToFalse();  
          } 
      }
      
   }
}

void fadeGreenLights(boolean limitFade){
   
   for(int i=0; i<ring.numPixels();i++){
      ring.setPixelColor(i,ring.Color(0,g,0));
      ring.show();
   } 
   
   g+=gspeed;
   
   if(g >= 255 || g<=0){
      gspeed *= -1; 
      
      if(limitFade){
          animationCount++;
          if(animationCount >= numFades){
            setStatesToFalse();  
          } 
      }
   }
}

void fadeBlueLights(boolean limitFade){
   
   for(int i=0; i<ring.numPixels();i++){
      ring.setPixelColor(i,ring.Color(0,0,b));
      ring.show();
   } 
   
   b+=bspeed;
   
   if(b >= 255 || b<=0){
      bspeed *= -1; 
      
      if(limitFade){
          animationCount++;
          if(animationCount >= numFades){
            setStatesToFalse();  
          } 
      }
      
   }
}

void switchOff(){
  for(uint16_t i=0; i<ring.numPixels(); i++) {
     ring.setPixelColor(i, offColor);
     ring.show();
  }
}

void setStatesToFalse(){
   //set all states to false
   red = false;
   green = false;
   blue = false;
   black = false;
   off = false;
   redBlink = false;
   greenBlink = false;
   blueBlink = false;
   fadeRed = false;
   fadeGreen = false;
   fadeBlue = false;
   
   // reset counter and common variables
   limitAnimation = false;
   animationCount = 0;
   currentPixel = 0;
   
}
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

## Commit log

2016-04-15 edited socket event
2016-04-15 created socket link between extension, server and peeoq
2016-04-22 implemented i2c code, not tested on pi yet
2016-04-24 working on socket links
2016-04-25 added note socket logic
2016-04-26 adding socket control panel
2016-04-27 added route and template for listening button
2016-04-27 tested i2c, added shutdown command
2016-04-28 added socket fall backs for remote control
2016-05-01 added arduino code for led and servo minis
2016-05-01 integrated i2c communication in led sketch
2016-05-01 created function to switch off all led states
2016-05-01 refining led code
2016-05-01 implementing count to repeat led animations
2016-05-01 adding servo functions
2016-05-01 using cmd para from node to set easing duration
2016-05-01 added function to reset servos to centre
    [servo_mini.ino]
2016-05-01 code to calibrate and find midpoint of each servo in microseconds
2016-05-02 added i2c functions
2016-05-03 added reset function, need to find angle values of servos
2016-05-03 arduino serial tester for processing sketch
2016-05-03 added function to send led animation
2016-05-03 added control panel and socket events
2016-05-03 prep for push to pi, uncommented i2c lines
2016-05-03 changed socket url
2016-05-03 added reboot socket message
2016-05-06 added socket links for testing
2016-05-06 added test socket links
2016-05-08 added socket to find pi's ip address for sshing into it
2016-05-09 added more socket links to control panel
2016-05-10 added more commands i2c
2016-05-10 uncommented i2c
2016-05-17 fixed reset servo bug which was recursively calling itself
2016-05-17 reduced gifshot number of frames
2016-05-17 added no and love socket
2016-05-17 reactivated i2c
2016-11-16 added global socket url in client side js, added i2c bus to package json
2016-12-02 added 3d files, circuit files and stl files
    [3mmspacerx12.stl, base_feetx1.stl, circuit_holderx2.stl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]
2016-12-17 implementing sockets to test movement via web
2016-12-17 added socket events to server
2016-12-19 more socket tests
2016-12-21 socket test end points
2016-12-21 socket test endpoints
2017-01-19 test sockets for debugging
2017-01-19 error in socket msg
2017-02-23 added sample config.js file
2017-03-02 small change to stewart top stl file to increase gap for wires
    [stewart_top.stl]
2017-03-02 restructured repo, moved hardware assets to sep repo
    [3mmspacerx12.stl, base_feetx1.stl, circuit_holderx2.stl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]
2017-03-14 separating out socket calls and cleaning frontend
2017-03-14 separated sockets into namespaces, switched to pug
2017-03-15 separated out sockets into sep modules
2017-03-17 corrected socket file ref typo
2017-03-17 fixed errors in animate function, working with demo sockets
2017-03-17 web controls sockets working
2017-03-17 added switch btns for local and remote gifs, bug fixes
2017-03-17 added led indicators in wifi and ble
2017-04-03 added socket endpoints for wifi connection
2017-04-06 socket bug
2017-04-06 socket wifi error on server

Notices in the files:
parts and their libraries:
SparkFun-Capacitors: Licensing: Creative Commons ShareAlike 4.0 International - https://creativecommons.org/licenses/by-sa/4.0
